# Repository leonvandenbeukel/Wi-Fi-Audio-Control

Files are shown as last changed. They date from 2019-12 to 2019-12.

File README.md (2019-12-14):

# Wi-Fi Audio Control

### Introduction

The basic idea is to split one audio signal into two separate audio signals. With a (mobile) app you can control the audio signals. The left and right volume of the first audio signal can be controlled with sliders. The second audio signal can be contoller with a 6 band equalizer.

### Components

| Component | Amount |
| - | - |
| ESP8266 Wi-Fi module | 1x |
| ADAU1401 SigmaDSP 28-/56-Bit Audio Processor  | 1x |
| 3.5mm jack input connector | 3x |
| Micro USB breakout board | 1x |
| Green 5mm LED and 220 ohm resistor (optional) | 1x |

### Schema

GPIO5 and GPIO4 are used for i2c (D1 and D2). Check this [reference](https://randomnerdtutorials.com/esp8266-pinout-reference-gpios/) for more info. The USB Breakout board used as a power supply from a regular 5V phone charger or USB from a PC or laptop.

| ADAU1401 | ESP8266 | USB board  | Jack In 1 | Jack Out 1 | Jack Out 2 |
| -  | - | - | - | - | - |
| +5V | VIN | +5V | | | |
| GND | GND | GND | | | |
| SDA | D2 (GPIO4) | | | | |
| SCL | D1 (GPIO5) | | | | |
| In GND | | | GND | | |
| In Left | | | In Left | | |
| In Right | | | In Right  | | |
| Out 1 GND | | | | Out 1 GND | |
| Out 1 Left | | | | Out 1 Left | |
| Out 1 Right | | | | Out 1 Right | |
| Out 2 GND | | | | | Out 2 GND |
| Out 2 Left | | | | | Out 2 Left  |
| Out 2 Right | | | | | Out 2 Right |

Optionally connect a status LED in series with a 220 ohm resistor to D5 (GPIO14) of the ESP8266 and to GND.

### Sigma Studio

To use this project you have to install Sigma Studio 4.x. After installing Sigma Studio you can open the file:

> \Sigma\Project.dspproj 

But before opening the project you have to create a folder:

> \Sigma\Output

You can use the buttons "Link Compile Download" and then "Export System Files" and then select the "Output" folder as destination. There is a post export command that copies the Project_IC* files to the Server folder. From the Arduino IDE these files are now included in the Arduino project. 

Add the file:

> SigmaStudioFW.h

from your "C:\Program Files\Analog Devices\SigmaStudio 4.x" to the "Server" folder also. Because of copyright you are not allowed to distribute this file.

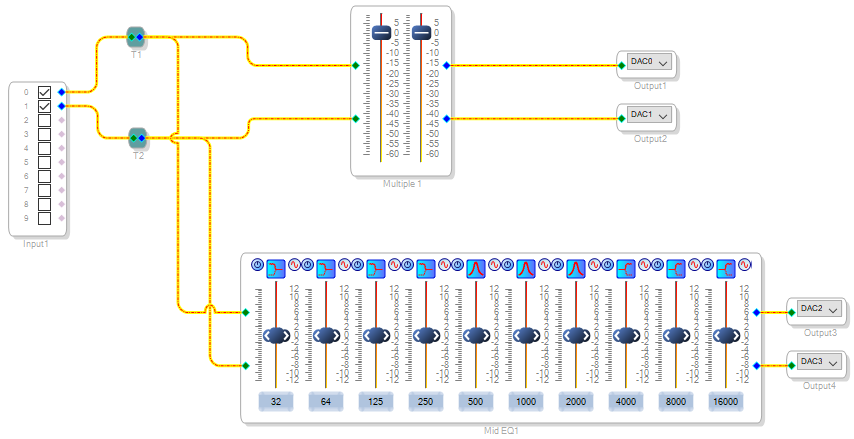
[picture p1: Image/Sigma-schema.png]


### Screenshot

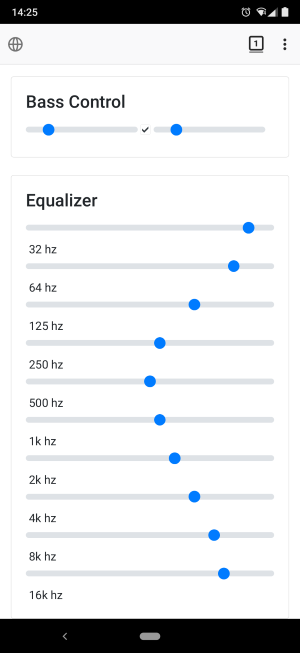
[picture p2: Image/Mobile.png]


### Prototype photo

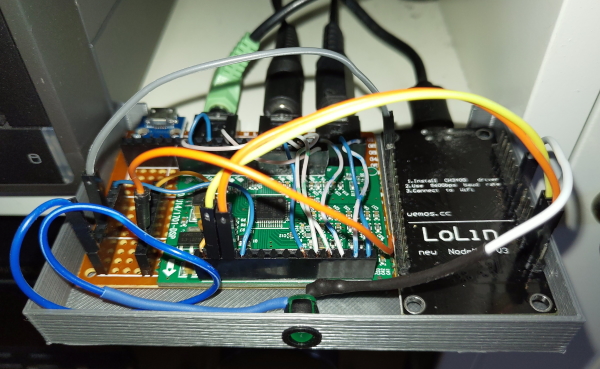
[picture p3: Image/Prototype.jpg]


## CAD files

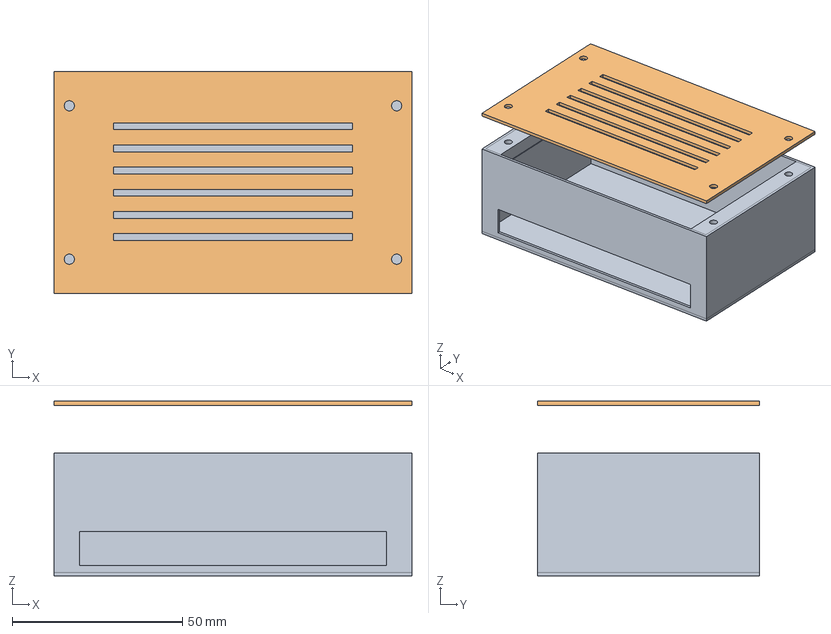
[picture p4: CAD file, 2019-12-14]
3DPrint/Model.FCStd
105.0 x 65.0 x 51.2 mm
Cover

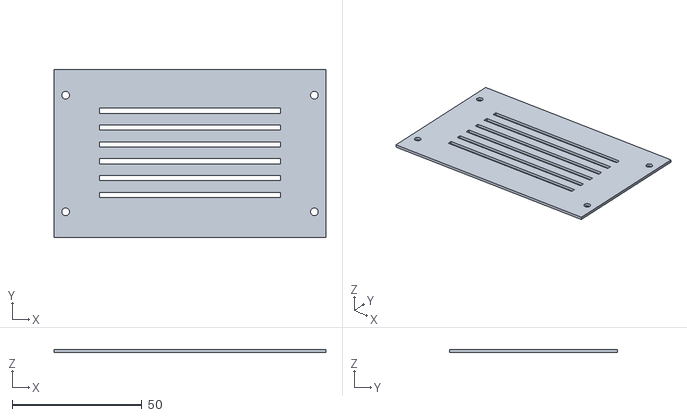
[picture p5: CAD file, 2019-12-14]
3DPrint/STL/Cover.stl
105.0 x 65.0 x 1.20

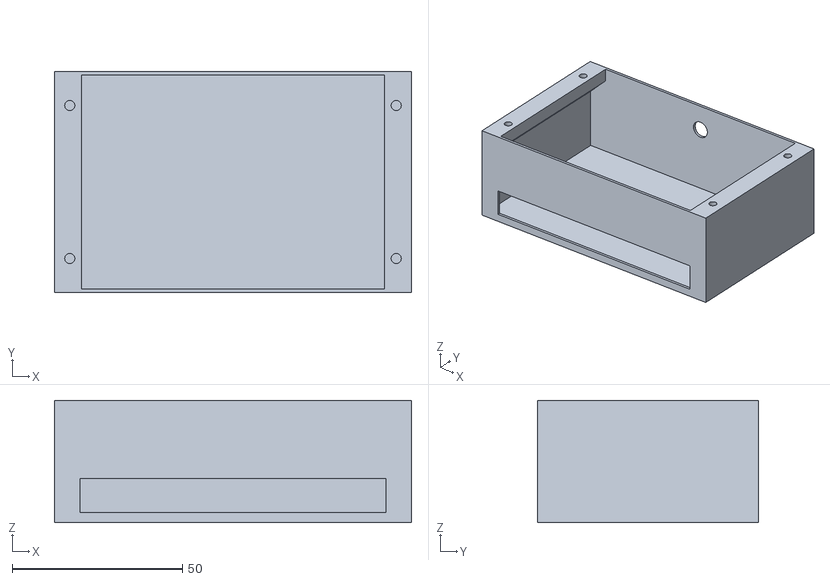
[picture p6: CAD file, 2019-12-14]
3DPrint/STL/Box.stl
105.0 x 65.0 x 36.0

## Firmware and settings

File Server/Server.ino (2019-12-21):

/*
 *  ESP8266 Wi-Fi Server that can receive http data and send it via i2c to the ADAU1401 audio processor
 *  
 *  Board: NodeMCU 1.0 (ESP-12E) / 115200 
 *  
 */
#include <Wire.h>
#include <EEPROM.h>
#include <ESP8266WiFi.h>
#include <WiFiClient.h>
#include <ESP8266WebServer.h>
#include <ESP8266mDNS.h>
#include "Credentials.h"
const char *ssid = UN;
const char *password = PW;

ESP8266WebServer server(80);

#include "Sigma.h"
#include "Project_IC_1.h"
#include "Project_IC_1_REG.h"
#include "Project_IC_1_PARAM.h"

#include "index.h"
const int led = 13;
const int statusLED = D5;

// Memory settings for eqband0-9, bassleft, bassright (with default values)
byte mem[12] = { 24, 24, 24, 24, 24, 24, 24, 24, 24, 24, 30, 30 };

void handleRoot() {
  digitalWrite(statusLED, HIGH);
  String s = MAIN_page; 
  server.send(200, "text/html", s); 
  digitalWrite(statusLED, LOW);
}

void getEQ() {
  digitalWrite(statusLED, HIGH);
  String message = "{\n";
  for (byte i=0; i<10; i++) {
    message += "\"band" + String(i) + "\":\"" + String(mem[i]) + "\"" + ((i<9) ? "," : "") + "\n";
  }  
  message += "}";
  server.send(200, "application/json; charset=utf-8", message);
  digitalWrite(statusLED, LOW);
}

void setEQ() {
  digitalWrite(statusLED, HIGH);
  byte band = server.arg(0).toInt();    // band: 0-9
  byte eqval = server.arg(1).toInt();   // eqval: 0-48
  String message;
  
  if (eqval > 48) {
    message = "EQ value is larger than the allowed index value of 48: " + String(eqval); 
    Serial.println(message);  
    server.send(200, "text/plain", message);
    return;        
  }
  
  mem[band] = eqval;
  EEPROM.put(band, eqval);
  EEPROM.commit();

  writeSigmaRegisterEQ(DEVICE_ADDR_IC_1, PARAM_ADDR_IC_1 + MOD_MIDEQ1_ALG0_STAGE0_B0_ADDR, band, eqval);  // Base address for EQ is used

  message = "EQ band " + String(band) + " changed to " + String(eqval); 
  Serial.println(message);  
  server.send(200, "text/plain", message);
  digitalWrite(statusLED, LOW);  
}

void getBass() {
  digitalWrite(statusLED, HIGH);
  String message = "{\n";
  message += "\"bassleft\":\"" + String(mem[10]) + "\",\n";
  message += "\"bassright\":\"" + String(mem[11]) + "\"\n";
  message += "}";
  server.send(200, "application/json; charset=utf-8", message);
  digitalWrite(statusLED, LOW);
}

void setBass() {
  digitalWrite(statusLED, HIGH);
  mem[10] = server.arg(0).toInt();
  mem[11] = server.arg(1).toInt();
  EEPROM.put(10, mem[10]);
  EEPROM.put(11, mem[11]);
  EEPROM.commit();
  String message;

  if (mem[10] > 65 || mem[11] > 65) {
    message = "Bass gain values are larger than the allowed index value of 65: " + String(mem[10]) + ", " + String(mem[11]); 
    Serial.println(message);  
    server.send(200, "text/plain", message);
    return;
  }
 
  writeSigmaRegisterBassGain(DEVICE_ADDR_IC_1, PARAM_ADDR_IC_1 + MOD_MULTIPLE1_ALG0_GAIN1940ALGNS1_ADDR, String(mem[10]));  // Left
  writeSigmaRegisterBassGain(DEVICE_ADDR_IC_1, PARAM_ADDR_IC_1 + MOD_MULTIPLE1_ALG1_GAIN1940ALGNS2_ADDR, String(mem[11]));  // Right
  //writeSigmaRegisterBassGainSafe(DEVICE_ADDR_IC_1, String(mem[10]));
  
  message = "Bass gain (left/right) changed to " + String(mem[10]) + ", " + String(mem[11]);
  Serial.println(message);
  server.send(200, "text/plain", message);
  digitalWrite(statusLED, LOW);  
}

void handleNotFound() {
  digitalWrite(led, 1);
  String message = "File Not Found\n\n";
  message += "URI: ";
  message += server.uri();
  message += "\nMethod: ";
  message += (server.method() == HTTP_GET) ? "GET" : "POST";
  message += "\nArguments: ";
  message += server.args();
  message += "\n";

  for (uint8_t i = 0; i < server.args(); i++) {
    message += " " + server.argName(i) + ": " + server.arg(i) + "\n";
  }

  server.send(404, "text/plain", message);
  digitalWrite(led, 0);
}

void setup(void) {
  
  Serial.begin(115200);
  
  Wire.begin();
  // On boot load program and parameter data to the ADAU
  // Check the function "default_download_IC_1()" under in the (generated) "Project_IC_1.h". In this file the correct order is used.
  Serial.println("Writing Core Register R0...");
  Sigma_write_register( DEVICE_ADDR_IC_1, REG_COREREGISTER_IC_1_ADDR, REG_COREREGISTER_IC_1_BYTE, R0_COREREGISTER_IC_1_Default );
  Serial.println("Writing Program data...");
  Sigma_write_register_block( DEVICE_ADDR_IC_1, PROGRAM_ADDR_IC_1, PROGRAM_SIZE_IC_1, Program_Data_IC_1 );
  Serial.println("Writing Parameter data...");
  Sigma_write_register_block( DEVICE_ADDR_IC_1, PARAM_ADDR_IC_1, PARAM_SIZE_IC_1, Param_Data_IC_1 );
  Serial.println("Writing Core Register R3...");
  Sigma_write_register( DEVICE_ADDR_IC_1, REG_COREREGISTER_IC_1_ADDR , R3_HWCONFIGURATION_IC_1_SIZE, R3_HWCONFIGURATION_IC_1_Default );
  Serial.println("Writing Core Register R4...");
  Sigma_write_register( DEVICE_ADDR_IC_1, REG_COREREGISTER_IC_1_ADDR, REG_COREREGISTER_IC_1_BYTE, R4_COREREGISTER_IC_1_Default );

  // Read 
  EEPROM.begin(sizeof(mem));
  for (byte i=0; i<sizeof(mem); i++) {
    byte b = 0;
    EEPROM.get(i, b);   
    Serial.print("EEPROM ");
    Serial.print(i);
    Serial.print(" ");
    Serial.println(b);
    
    if (b > 0)
      mem[i] = b;    
  } 
  
  Serial.println("Restoring memory settings...");

  // Set bass registers
  if (mem[10] < 66)
    writeSigmaRegisterBassGain(DEVICE_ADDR_IC_1, PARAM_ADDR_IC_1 + MOD_MULTIPLE1_ALG0_GAIN1940ALGNS1_ADDR, String(mem[10]));  // Left

  if (mem[11] < 66)
    writeSigmaRegisterBassGain(DEVICE_ADDR_IC_1, PARAM_ADDR_IC_1 + MOD_MULTIPLE1_ALG1_GAIN1940ALGNS2_ADDR, String(mem[11]));  // Right

  // Set eq registers
  for (byte i=0; i<10; i++) {
    if (mem[i] < 49) 
      writeSigmaRegisterEQ(DEVICE_ADDR_IC_1, PARAM_ADDR_IC_1 + MOD_MIDEQ1_ALG0_STAGE0_B0_ADDR, i, mem[i]);  // Base address for EQ is used  
  }

  pinMode(led, OUTPUT);
  pinMode(statusLED, OUTPUT);
  digitalWrite(led, 0);
  WiFi.mode(WIFI_STA);
  WiFi.begin(ssid, password);
  Serial.println("");
  bool LEDon = false;

  // Wait for connection
  while (WiFi.status() != WL_CONNECTED) {
    delay(500);
    Serial.print(".");
    LEDon = !LEDon;
    digitalWrite(statusLED, LEDon);
  }
  digitalWrite(statusLED, LOW);

  Serial.println("");
  Serial.print("Connected to ");
  Serial.println(ssid);
  Serial.print("IP address: ");
  Serial.println(WiFi.localIP());

  if (MDNS.begin("esp8266")) {
    Serial.println("MDNS responder started");
  }

  server.on("/", handleRoot);
  server.on("/getEq", getEQ);  
  server.on("/setEq", setEQ);  
  server.on("/getBass", getBass);
  server.on("/setBass", setBass);  
  server.onNotFound(handleNotFound);
  server.begin();
  Serial.println("HTTP server started");
}

void loop(void) {
  server.handleClient();
  MDNS.update();
}

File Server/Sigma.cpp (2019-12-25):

/*
 * Based on Martin van den Beukel's code to Boot Adau1701 via i2c from an Arduino Nano 5V 16MHz and send different parameters to the ADAU
 * This also seems to works for ESP8266. Translated some comments to English and added writeSigmaRegisterBassGain and writeSigmaRegisterEQ
 */
#include "Arduino.h"
#include <Wire.h>
#include "Equalizer.h"
#define paramLength 4
byte paramData[paramLength];

/*
 * Implementation of the macro/function defined in "SigmaStudioFW.h" to write a memory block to the Adau1701 via i2c
 * 
 * Datatypes of the parameters are determined by the header files from SigmaStudio and info from https://www.arduino.cc: 
 * - byte for 8 bits and - short for 16 bits.
 *
 * Check http://www.audiodevelopers.com/5-the-microprocessor-how-to-control-the-dsp/ for an example.
 * Wire.beginTranmission shifts the devAddress 1 bit to the left. That's why shift 1 time to the right the first time
 */
void Sigma_write_register_block(byte devAddress, short address, short dataLength, const byte *data ) {
  int dataType = 0;

  if( address == 0 ) {
    // parameter data starts at address 0x0000; 4 bytes data word
    dataType = 4;
  } else {
    // program dat starts at address 0x0400; 5 bytes data word
    dataType = 5;
  }
  // short = 16 bits = needed to address each byte:
  for( short x = 0; x < dataLength; x++ ) {
    Wire.beginTransmission(devAddress >> 1);
    Wire.write(highByte(address));
    Wire.write(lowByte(address));
    for( short y = 0; y < dataType; y++ ) {
      // use pgm_read_byte_near() to read from the program space
      byte dataByte = pgm_read_byte_near(data+x+y);
      Wire.write(dataByte);
    }
    Wire.endTransmission();
    // next address of adau parameter or program memory
    address++;
    // skip the bytes in data[] that are send in the inner for loop
    x = x + dataType - 1;
  }
}

// Implementation of the macro/function defined in "SigmaStudioFW.h" to write to the Adau1701 via i2c
// Note that this is a direct write, not using the safeload registers.
// Note that the arduino has an i2c buffer of 32 bytes; the dataLength must be less than that.
void Sigma_write_register(byte devAddress, short address, short dataLength, byte *data ) {
  Wire.beginTransmission(devAddress >> 1);
  Wire.write(highByte(address));
  Wire.write(lowByte(address));
  for( short x = 0; x < dataLength; x++ ) {
    Wire.write(data[x]);
  }
  Wire.endTransmission();
}

// Implementation of the macro/function defined in "SigmaStudioFW.h" to convert an integer to the 5.23 format of the Adau1701
void Sigmastudiotype_integer_convert( int32_t value ) {
  //still empty
}

// Implementation of the macro/function defined in "SigmaStudioFW.h" to convert a float to the 5.23 format of the Adau1701
void Sigmastudiotype_fixpoint_convert( float value ) {
  int32_t paramValue = (int32_t)( value * (1L << 23) );
  paramData[3] = paramValue & 0xFF;
  paramData[2] = (paramValue >> 8) & 0xFF;
  paramData[1] = (paramValue >> 16) & 0xFF;
  paramData[0] = (paramValue >> 24) & 0xFF;
}

void writeSigmaRegisterBassGain(byte devAddress, short address, String value) {
  int ival = value.toInt();
  long lval = map(ival, 0, 65, 1, 1995);
  float fval = lval / 1000.0;
    
  Sigmastudiotype_fixpoint_convert(fval);
  Sigma_write_register(devAddress, address, paramLength, paramData);
}

void writeSigmaRegisterBassGainSafe(byte devAddress, String value) {

  // Write the data to the ADAU1401 safe load data registers (starting at 0x0810 to 0x0814 according to the datasheet)
  int ival = value.toInt();
  long lval = map(ival, 0, 65, 1, 1995);
  float fval = lval / 1000.0;    
  Sigmastudiotype_fixpoint_convert(fval);
  Sigma_write_register(devAddress, 0x0810, paramLength, paramData);
  //Sigma_write_register(devAddress, 0x0811, paramLength, paramData);
  
  // Write the addresses to write to, to the ADAU1401 safe load address registers (starting at 0x0815 to 0x0819 according to the datasheet)
  Sigmastudiotype_fixpoint_convert(1);
  Sigma_write_register(devAddress, 0x0815, paramLength, paramData);
  //Sigmastudiotype_fixpoint_convert(1);
  //Sigma_write_register(devAddress, 0x0816, paramLength, paramData);

  // Finally write transfer control bit to the core control register (register 0x081C bit D5 according to the datasheet)
  short IST = 60; // REG_COREREGISTER_IC_1_VALUE | 1 << 5 --> 60 (0x3C)
  Sigmastudiotype_fixpoint_convert(60);
  Sigma_write_register(devAddress, 0x081C, paramLength, paramData);

//  // Gain LEFT
//  Wire.beginTransmission(devAddress >> 1);
//  // address
//  Wire.write(0x00);
//  Wire.write(0x00);
//  // data
//  Wire.write(0x00);
//  Wire.write(0x00);
//  Wire.write(0x20);
//  Wire.write(0xC5);
//  Wire.endTransmission();  
//
//  // Gain RIGHT
//  Wire.beginTransmission(devAddress >> 1);
//  // address
//  Wire.write(0x00);
//  Wire.write(0x01);
//  // data
//  Wire.write(0x00);
//  Wire.write(0x00);
//  Wire.write(0x20);
//  Wire.write(0xC5);
//  Wire.endTransmission();  
//
//  delay(2000);
//
//   // Gain LEFT
//  Wire.beginTransmission(devAddress >> 1);
//  // address
//  Wire.write(0x00);
//  Wire.write(0x00);
//  // data
//  Wire.write(0x00);
//  Wire.write(0x00);
//  Wire.write(0x67);
//  Wire.write(0x9F);
//  Wire.endTransmission();  
//
//  // Gain RIGHT
//  Wire.beginTransmission(devAddress >> 1);
//  // address
//  Wire.write(0x00);
//  Wire.write(0x01);
//  // data
//  Wire.write(0x00);
//  Wire.write(0x00);
//  Wire.write(0x67);
//  Wire.write(0x9F);
//  Wire.endTransmission();  
  
}

void writeSigmaRegisterEQ(byte devAddress, short baseAddress, byte band, byte value) {

  Sigma_write_register(devAddress, baseAddress + (band * 5) + 0, 4, bands[band][value][0]);
  Sigma_write_register(devAddress, baseAddress + (band * 5) + 1, 4, bands[band][value][1]);
  Sigma_write_register(devAddress, baseAddress + (band * 5) + 2, 4, bands[band][value][2]);
  Sigma_write_register(devAddress, baseAddress + (band * 5) + 3, 4, bands[band][value][3]);
  Sigma_write_register(devAddress, baseAddress + (band * 5) + 4, 4, bands[band][value][4]);
  
}

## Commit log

2019-12-07 Started with equalizer and first 100Hz now works
2019-12-08 Added 500Hz and created a tool for converting hex arrays
2019-12-14 Added box model for 3D printing and added LED status support
    [Box.stl, Cover.stl, Model.FCStd]
2019-12-14 Added prototype photo
2019-12-14 Scaled prototype photo
